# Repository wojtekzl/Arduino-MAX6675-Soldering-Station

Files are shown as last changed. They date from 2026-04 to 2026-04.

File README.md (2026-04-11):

# Arduino MAX6675 Soldering Station

[English version below](#english-version) | [Przejdź do wersji polskiej](#polska-wersja)

---
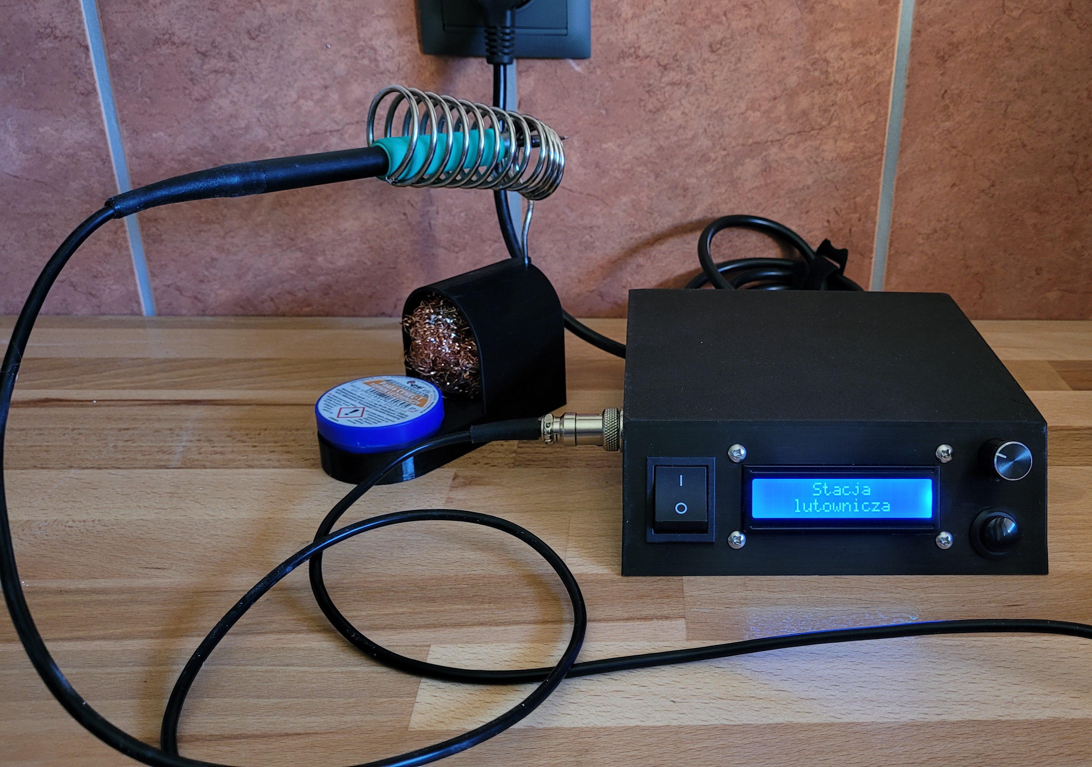
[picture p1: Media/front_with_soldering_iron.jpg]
Main Photo

---

## Polska Wersja

### O Projekcie
Zaawansowana stacja lutownicza DIY oparta na mikrokontrolerze Arduino Nano. Projekt łączy precyzyjne sterowanie cyfrowe z ergonomiczną obudową 3D. System wykorzystuje termoparę typu K (MAX6675) oraz tranzystor MOSFET do sterowania grzałką 12V.

### Główne Funkcjonalności
* **Sterowanie PID:** Autorski algorytm zapewniający stabilną temperaturę bez przeregulowań (overshoot).
* **Filtracja EMA (Exponential Moving Average):** Wykładnicze wygładzanie sygnału z potencjometru - eliminuje "skakanie" nastawy spowodowane szumami zasilacza.
* **Tryb Sleep:** Funkcja szybkiego schłodzenia grotu do 100°C po naciśnięciu przycisku Mode.
* **Synchronizacja Pomiaru:** Czasowe wyłączanie grzałki (PWM=0) podczas odczytu temperatury, co eliminuje błędy pomiarowe wywołane zakłóceniami EM.

### Schemat
Pełny schemat połączeń znajduje się w pliku `Hardware/diagram.png`.
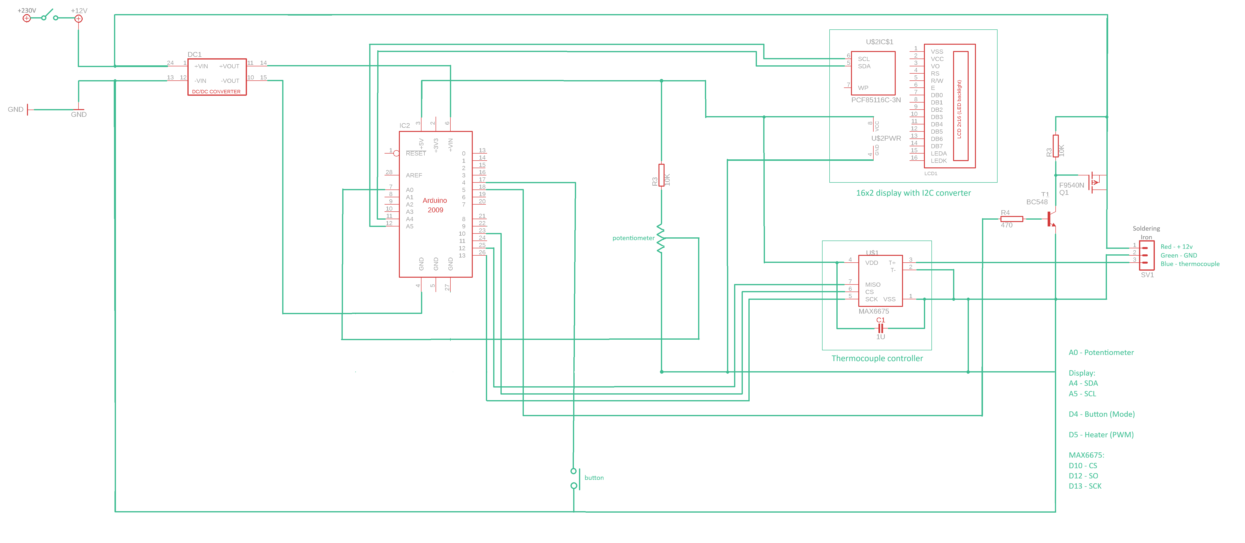
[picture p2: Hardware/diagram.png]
Diagram


### Struktura Repozytorium
* `/Firmware/` - Kod źródłowy Arduino (PID & Logic).
* `/Hardware/` - Schemat ideowy (`diagram.png`) wraz z rozpiską pinów.
* `/3D Models/` - Kompletny projekt obudowy w formacie `.3mf`.
* `/Media/` - Dokumentacja fotograficzna gotowego urządzenia.

### Inspiracje
Projekt powstał inspirując się projektem z kanału **[Zrobisz to SAM](https://www.youtube.com/@zrobisz_to_sam_)**. 
W mojej wersji wprowadziłem następujące zmiany i usprawnienia:
1. Pełna implementacja algorytmu PID dla lepszej stabilności cieplnej.
2. Dodanie filtracji cyfrowej (EMA) dla sygnału z potencjometru.
3. Projektowanie od podstaw obudowy 3D razem z ergonomiczną podpórką.
4. Usunięcie zbędnych linijek kodu.

### UWAGA
Projekt dotyczy urządzeń pracujących z wysoką temperaturą oraz napięciem sieciowym. Nie ponoszę odpowiedzialności za jakiekolwiek szkody materialne, uszczerbek na zdrowiu lub inne straty powstałe w wyniku budowy lub użytkowania tego urządzenia. Wszystko robisz na własną odpowiedzialność. Pamiętaj o zachowaniu zasad BHP!

---

## English Version

### About The Project
An advanced DIY soldering station powered by an Arduino Nano microcontroller. This project combines precise digital control with an ergonomic 3D-printed enclosure. The system utilizes a K-type thermocouple (MAX6675) and a MOSFET transistor to drive a 12V heating element.

### Key Features
* **PID Control:** Custom-tuned algorithm ensuring stable temperature without overshooting.
* **EMA Filtering (Exponential Moving Average):** Software-based smoothing of the potentiometer signal - eliminates setpoint "jitter" caused by power supply noise.
* **Sleep Mode:** Rapid tip cooldown to 100°C at the press of the Mode button.
* **Measurement Synchronization:** Momentary heater deactivation (PWM=0) during temperature readouts to eliminate measurement errors caused by electromagnetic interference (EMI).

### Diagram
The full wiring diagram is available in the `Hardware/diagram.png` file.
Diagram

### Repository Structure
* `/Firmware/` - Arduino source code (PID & Logic).
* `/Hardware/` - Circuit diagram (`diagram.png`) with pinout configuration.
* `/3D Models/` - Complete 3D enclosure project in `.3mf` format.
* `/Media/` - Photographic documentation of the finished device.

### Inspirations
This project was inspired by the project from the **[Zrobisz to SAM](https://www.youtube.com/@zrobisz_to_sam_)** YouTube channel.
In my version, I have introduced the following improvements:
1. Full PID algorithm implementation for superior thermal stability.
2. Added digital filtering (EMA) for the potentiometer input signal.
3. From-scratch 3D design of the enclosure, including an ergonomic iron stand.
4. Removed unnecessary lines of code for better optimization.

### DISCLAIMER
This project involves high temperatures and mains voltage. I am not responsible for any property damage, personal injury, or other losses resulting from the construction or use of this device. You build and use it at your own risk. Always follow safety guidelines!

---

## Galeria / Gallery
| Tryb Pracy / Heat Mode | Wnętrze / Inside | Podpórka / Stand |
|---|---|---|
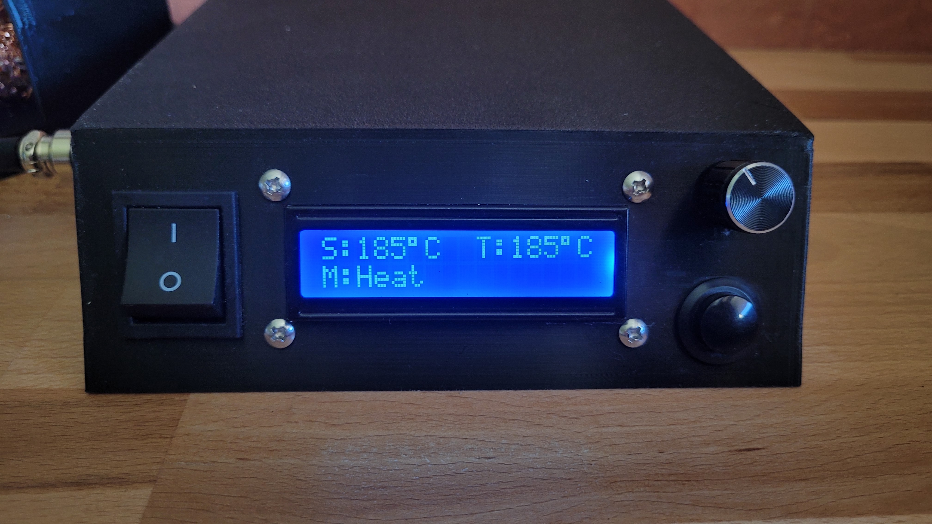
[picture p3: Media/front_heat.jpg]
Heat
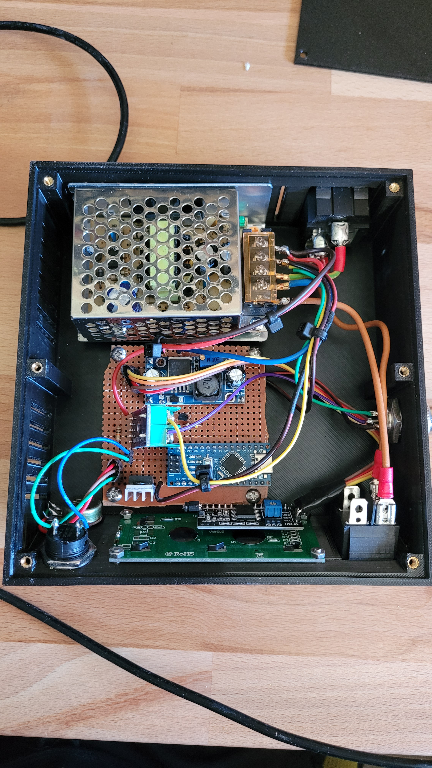
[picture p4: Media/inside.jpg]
Inside
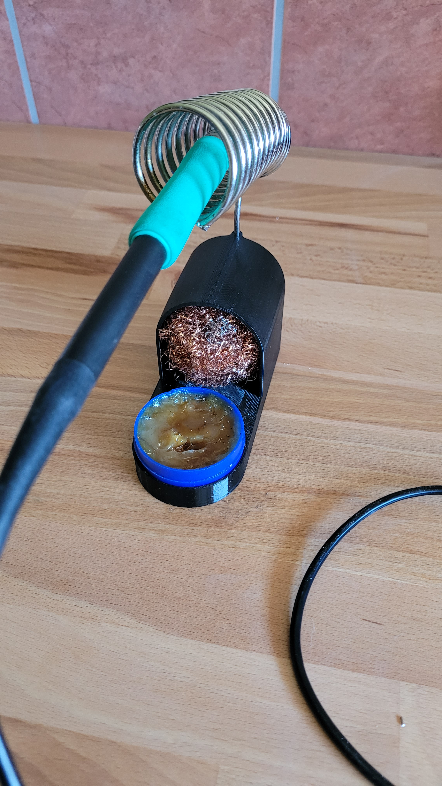
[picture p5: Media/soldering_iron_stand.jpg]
Stand
|  |  |  |

---
*Created by Wojciech Z | MIT License | 2026*

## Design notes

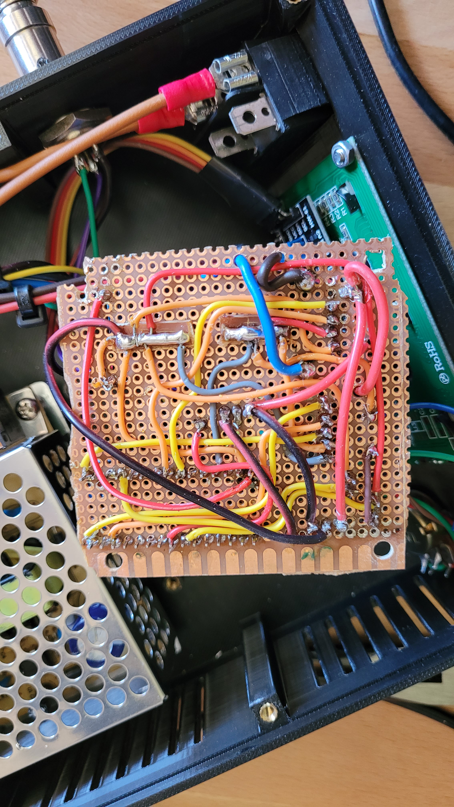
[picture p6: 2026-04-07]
Media/circuit_board.jpg

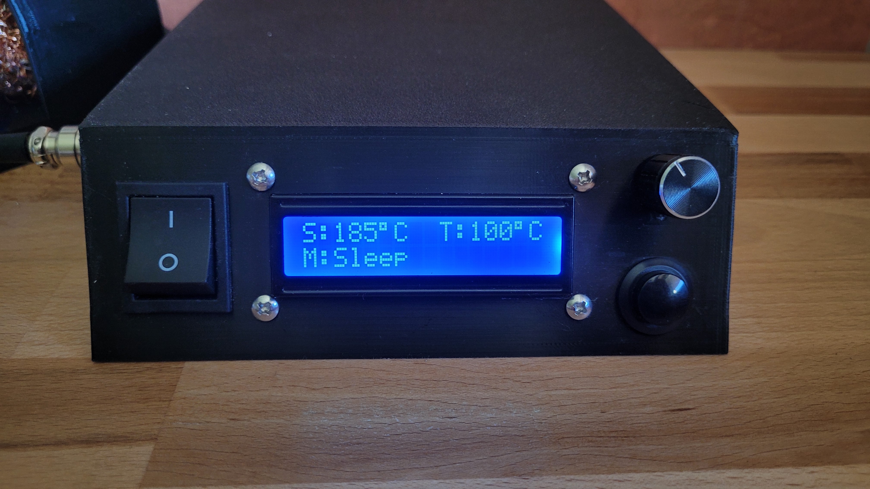
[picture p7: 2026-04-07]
Media/front_sleep.jpg

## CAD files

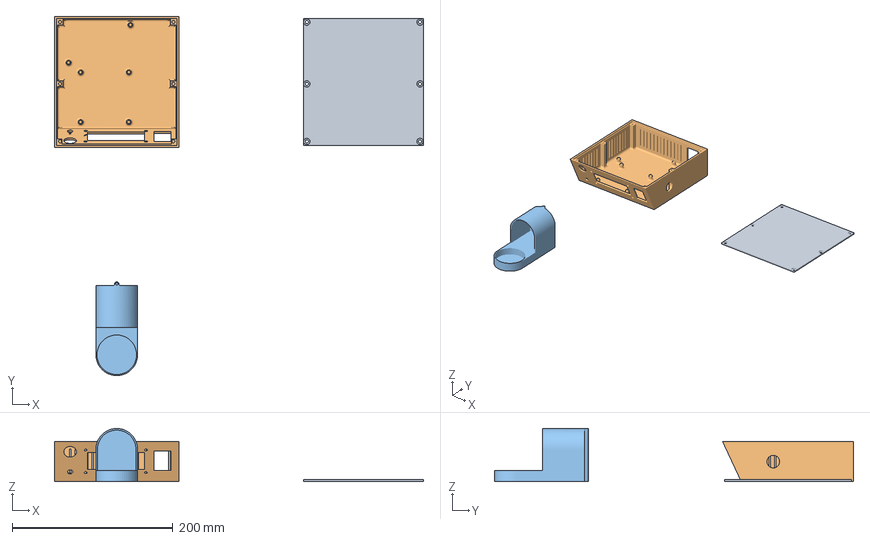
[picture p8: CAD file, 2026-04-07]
3D Models/3D_model.3mf
459.5 x 447.3 x 66.0 mm
Bryła16
Bryła4
szuflada.stl_21

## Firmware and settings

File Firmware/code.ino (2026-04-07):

#include <Wire.h>
#include <LiquidCrystal_I2C.h>
#include "max6675.h"

// Hardware Configuration
const int soPin = 12;
const int csPin = 10;
const int sckPin = 13;
const int PWM_pin = 5;
const int modeButtonPin = 4;
const int pot_pin = A0;

// Objects
LiquidCrystal_I2C lcd(0x27, 16, 2);
MAX6675 thermo(sckPin, csPin, soPin);

// Custom Characters
byte l_polskie[8] = { B01100, B00100, B00110, B00100, B01100, B00100, B01110, B00000 };
byte a_polskie[8] = { B00000, B01110, B00001, B01111, B10001, B01111, B00001, B00010 };

// Control Variables
float temperature_read = 0.0;
int set_temperature = 100;
int heat_temperature = 100;
float PID_error = 0, previous_error = 0, PID_i = 0;
int PID_value = 0;

// PID Tuning Parameters
const int kp = 20; 
const float ki = 0.3; 
const int kd = 10; 

// Limits
const int tempMin = 100;
const int tempMax = 300; 

// State & Timing
unsigned long lastLoop = 0;
unsigned long lastDebounceTime = 0;
const unsigned long debounceDelay = 50;
bool isSleep = false;
bool sensorError = false;
bool lastButtonReading = HIGH;
bool stableButtonState = HIGH;

// Potentiometer Filter
int lastPotValue = 0;
float smoothedPot = 0;

void setup() {
    lcd.init();
    lcd.backlight();
    lcd.createChar(0, l_polskie);
    lcd.createChar(1, a_polskie);
    
    showWelcomeScreen();

    pinMode(PWM_pin, OUTPUT);
    digitalWrite(PWM_pin, LOW);
    pinMode(modeButtonPin, INPUT_PULLUP);

    smoothedPot = analogRead(pot_pin);
    delay(2000);
    lcd.clear();
    refresh_screen();
}

void loop() {
    unsigned long currentTime = millis();

    // 1. Potentiometer logic (EMA Filter)
    int rawPot = analogRead(pot_pin);
    smoothedPot = (smoothedPot * 0.9) + (rawPot * 0.1);
    
    if (abs((int)smoothedPot - lastPotValue) > 8) {
        int mapped = map((int)smoothedPot, 0, 490, tempMin, tempMax); 
        int new_set = (constrain(mapped, tempMin, tempMax) / 5) * 5;

        if (new_set != set_temperature) {
            set_temperature = new_set;
            if (!isSleep) heat_temperature = set_temperature;
            lastPotValue = (int)smoothedPot;
            refresh_screen(); 
        }
    }

    handleButton(currentTime);

    // 2. Main Control Loop (Sensor & PID)
    if (currentTime - lastLoop >= 2000) {
        digitalWrite(PWM_pin, LOW); 
        delay(250); 

        float raw_t = thermo.readCelsius();

        if (raw_t <= 1 || raw_t > 500 || isnan(raw_t)) {
            sensorError = true;
            PID_value = 0;
        } else {
            sensorError = false;
            processTemperature(raw_t);
            calculatePID();
        }

        updateDynamicDisplay();
        lastLoop = millis();
    }

    // 3. Power Output (PWM)
    applyPower(currentTime);
}

void processTemperature(float raw_t) {
    float compensation = (set_temperature < 150) ? 1.15 : 1.3;
    float candidate = raw_t * compensation;

    if (abs(candidate - temperature_read) < 80 || temperature_read == 0) {
        temperature_read = candidate;
    }
}

void calculatePID() {
    PID_error = heat_temperature - temperature_read;
    
    if (abs(PID_error) < 15) PID_i += (ki * PID_error);
    else PID_i = 0; 
    
    float p_term = kp * PID_error;
    float d_term = kd * (PID_error - previous_error);

    int max_p = (PID_error < 10) ? 75 : (PID_error < 20) ? 120 : 200;
    PID_value = constrain((int)(p_term + PID_i + d_term), 0, max_p);
    previous_error = PID_error;
}

void applyPower(unsigned long now) {
    static unsigned long heatTimer = 0;
    if (now - heatTimer >= 1000) heatTimer = now;

    unsigned long onTime = map(PID_value, 0, 255, 0, 1000);
    bool isMeasuring = (now - lastLoop > 1600);

    if (!sensorError && !isMeasuring && (now - heatTimer < onTime) && PID_value > 0) {
        digitalWrite(PWM_pin, HIGH);
    } else {
        digitalWrite(PWM_pin, LOW);
    }
}
 
void handleButton(unsigned long now) {
    bool reading = digitalRead(modeButtonPin);
    if (reading != lastButtonReading) lastDebounceTime = now;

    if (now - lastDebounceTime > debounceDelay) {
        if (stableButtonState == HIGH && reading == LOW) {
            isSleep = !isSleep;
            heat_temperature = isSleep ? 100 : set_temperature;
            PID_i = 0; 
            refresh_screen();
        }
        stableButtonState = reading;
    }
    lastButtonReading = reading;
}

void showWelcomeScreen() {
    lcd.setCursor(5, 0); lcd.print("Stacja");
    lcd.setCursor(3, 1); lcd.print("lutownicza");
}

void updateDynamicDisplay() {
    lcd.setCursor(9, 0);
    lcd.print("T:");
    if (sensorError) lcd.print("error");
    else {
        lcd.print((int)temperature_read);
        lcd.print((char)223); lcd.print("C  "); 
    }
}

void refresh_screen() {
    lcd.setCursor(0, 0);
    lcd.print("S:"); lcd.print(set_temperature);
    lcd.print((char)223); lcd.print("C  "); 

    lcd.setCursor(0, 1);
    lcd.print("M:");
    lcd.print(isSleep ? "Sleep   " : "Heat    ");
}

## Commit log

2026-04-07 Add Arduino PID control firmware with EMA filtering
2026-04-07 Add 3D printable models for case and iron stand
2026-04-07 Add circuit diagram and pinout configuration
